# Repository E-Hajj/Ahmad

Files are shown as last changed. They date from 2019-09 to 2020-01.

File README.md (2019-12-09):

# Solar Panel Gazebo Build Instructions

## General info

This repository contains the implementation of a feasibility study for automatic readings of a solar panel. The project will heavily focus on measuring the current of the solar panel in Amps.

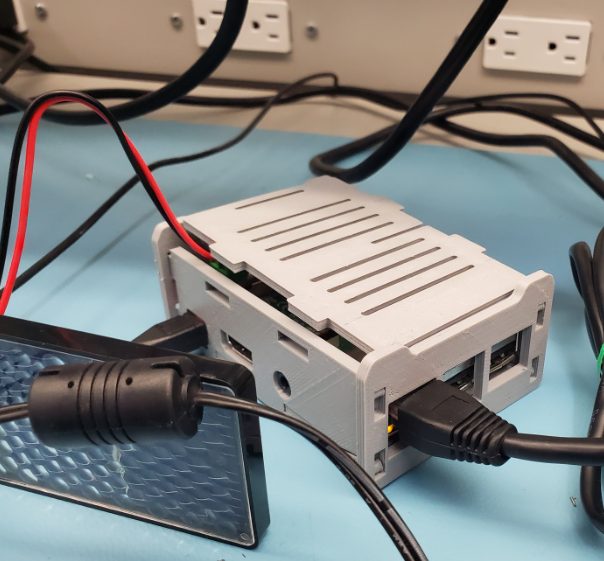
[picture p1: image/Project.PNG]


## Table of contents
* [General info](#general-info)
* [Repository Structure](#Repository-Structure)
* [Requirements](#Requirements)
* [PCB](#PCB)
* [3D Print](#3D-Printing)
* [Soldering](#Soldering)
* [Unit Testing](#Unit-Testing)
* [Assembly](#Assembly)
* [Product Testing](#Product-Testing)

## Repository Structure 

1.  [Documentation](https://github.com/E-Hajj/Ahmad/tree/master/documentation) of the solar repository.  
2.  [Code](https://github.com/E-Hajj/Ahmad/tree/master/Code) contains the source code to interact with the solar panel and sensors.   
3.  [Electronics](https://github.com/E-Hajj/Ahmad/tree/master/Electronics) holds the contents of the PCB design,schematic and breadboard design.  
4.  [Raspberry pi Case](https://github.com/E-Hajj/Ahmad/tree/master/Raspberry%20pi%20case) contains the required build for the case.  
5.  [Images](https://github.com/E-Hajj/Ahmad/tree/master/image) of the project.

## Requirements

In this project you will need the required components to build this project. The total budget is  $195.34 not including tax or shipping or any other fees and prices may rise or fall. Depending if you have amazon prime and able to go to Sayal Electronics your products should arrive 1 to 5 days. While waiting for your components to arrive i would recommended starting on the pcb and 3d printing.

* **Raspbery pi 3**   *$114*
  * Power supply 2A micro usb 
  * Ethernet cable and hdmi cable
  * Sd card for the software
  * If you dont own an raspberry pi 3 i would recommed buying one from [Amazon](https://www.amazon.ca/s?k=raspberry+pi+3&ref=nb_sb_noss_2) or [Sayal Electronics](https://secure.sayal.com/STORE2/index.php). 
* **Acs712 (current sensor)** *$13.99*
  * I would recoomend getting it from [Amazon](https://www.amazon.ca/COVVY-Current-Arduino-ACS712ELC-20A-Indicator/dp/B07TQ5M9MP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) becuase it comes in a pack of 2 incase one breaks or is faulty.  
* **Ads1115 (Analog to Digital Converter)** *$15.99*
   * [Amazon](https://www.amazon.ca/gp/product/B07GBYY54P/ref=ppx_yo_dt_b_asin_title_o04_s00?ie=UTF8&psc=1) would be a great option for this component, because the shipping is very quick for this.
* **Velleman Solar Cell 1V 200MA** *$7.95*
   * I would strongly recommend  [Sayal Electronics](https://secure.sayal.com/STORE2/index.php) sinces its cheaper and always in stock.
* **Wire Stripper/cutters** *$6.56*
  * If you already own them please make sure they work and are well sharpened.
   * [Amazon](https://www.amazon.ca/gp/product/B005HQR1YK/ref=ppx_yo_dt_b_asin_title_o02_s00?ie=UTF8&psc=1)
* **Safety eyewear** *$2.91*
  * Very important since you will be soldering and cutting and stripping wire 
  * Safety First
* **Soldering kit** *$29.99*
  * you will need some sort of soldering iron and solder to put together the PCB.
  * [Amazon](https://www.amazon.ca/gp/product/B07L3VNMKX/ref=ppx_yo_dt_b_asin_title_o03_s00?ie=UTF8&psc=1)
* **Socket kit** *$3.95*
  * 6 pin socket
  * 3 pin socket 
  * 10 pin socket
  * [Sayal Electronics](https://secure.sayal.com/STORE2/View_SHOP.php?SKU=241160)
  
 ## PCB
 I would strongly recommend ordering your parts before you continue on to this part. Usually the parts will take 3 to 5 days due to shipping unless you have amazon prime then it should take a day or two. While waiting for the parts you should start working on the breadboard and PCB board. Creating the PCB will take time depending where you get it made so i would strongly recommed that you get it made right away as it would take time.
 
 1. Go to [Electronics](https://github.com/E-Hajj/Ahmad/tree/master/Electronics) and download the Fritzing file of version two.
 2. When you open the File you will need to click on File->Export->Production->Gerber desing
 3. You will need to find a place that prints PCBs and get it made.
 4. while you wait on that you can start working on the breadboard. Looking at the fritzing file select the breadboard view and see how the circuit is made. 
 5. follow all the connections made. Even if you dont have the sensors you can have it all setup and ready.
 
 ## 3D Printing
 While you wait for the components to come in you can start working on the raspberry pi case. This folder will contain all the certian pieces need to assemble the case. It comes in like lego pieces that gets assembled together. This folder [Raspberry pi Case](https://github.com/E-Hajj/Ahmad/tree/master/Raspberry%20pi%20case) contains all the .stl files that needs printing. Download all the files needed.  
* [Back Panel](Raspberry%20pi%20case/back_panel_SD.stl)  
* [Bottom Panel](Raspberry%20pi%20case/bottom_panel.stl)  
* [Front Panel](Raspberry%20pi%20case/front_panel_USB.stl)  
* [Side Panel](Raspberry%20pi%20case/side_panel_GPIO_updated.stl)  
* [Side Panel HDMI](Raspberry%20pi%20case/side_panel_HDMI.stl)  
* [Top Panel](Raspberry%20pi%20case/top_panel.stl)  
 You will need a type of software that connects to 3d printers and reads .stl files. I would recommend [Cura](https://ultimaker.com/software/ultimaker-cura) since its very easy and simple to operate. 
 1. Open all the .stl files that you downloaded in Cura.
 
 2. Select the type of 3D printer you will be using.
 
 2. The top right Settings in Cura is the setting or style of the print it looks like this.
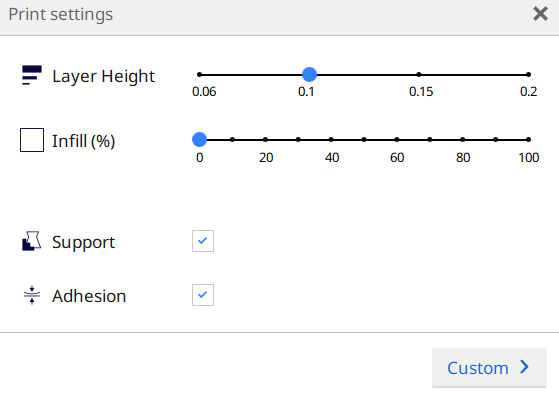
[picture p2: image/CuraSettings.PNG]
Cura
  
  
 3. Once completed you will need to press slice on the bottom right. Slice while create a .gcode file that will need to be uploaded to your 3d printer. Depending on your 3D printer you may need to upload it to an SD card and insert it in the printer. 
 
 4. Once placed you will need to select the file to start printing.  
 
 5. While printing please make sure you check on it every so often because the filler might run out or get stuck or the flat base plate might.

 ## Soldering 
 * If youve never soldered before i would recommend you to watch these videos on how to solder and safety as well. [Video](https://www.youtube.com/watch?v=BLfXXRfRIzY&list=PLQ32vZrF5U2lFOJTtZDytBWBYVLNp4RYz)
 1. When soldering the PCB make sure the 6 pin socket is at the bottom of the board.
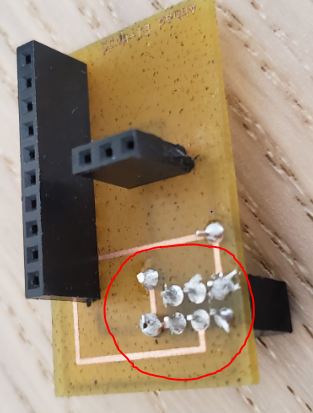
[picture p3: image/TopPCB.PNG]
 
 2. Line up the 10 and 3 pin sockets to their corresponding connection as seens in this picture, Then solder.
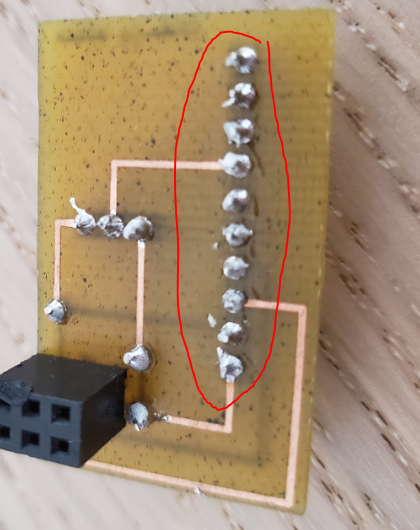
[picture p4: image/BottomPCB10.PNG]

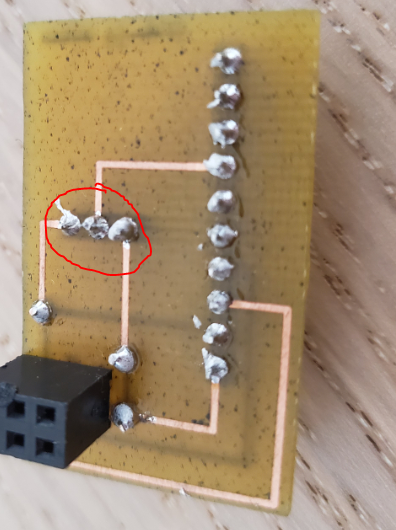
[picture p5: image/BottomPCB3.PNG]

 3. Solder All via's by runnings wire through it and soldering each side.
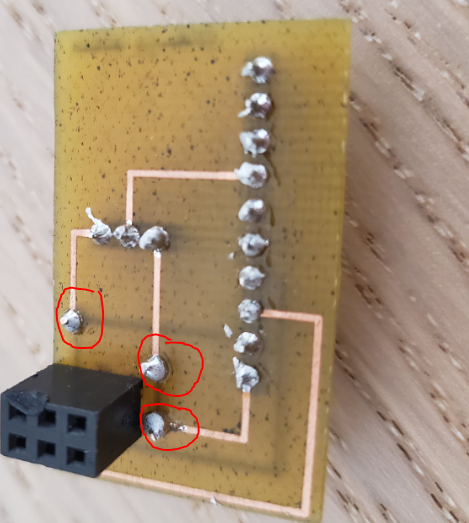
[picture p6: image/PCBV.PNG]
 

 4. Once completed you must check if all pins are fully covered in solder an are stable. 
 5. To make sure all connections are fine and the board isnt damage you must use a digital multi meter and measure the resistance between each ports. The readings should be overload for the ports that shouldnt be connected. The corresponding pin to pin should show a little resisitance.

 ## Unit Testing 
 
 Once all Parts have arrived you can start testing your sensors before you test them on the PCB board.  
 1. Setup  
     1.a if you havnt connected the parts on the breadboard please follow  [PCB](#PCB)   
     1.b You will need to be able to connect to your pi. If you havn't booted the operating sytem please follow this link. [Link]( https://www.raspberrypi.org/help/noobs-setup/2/)  
     1.c Once thats completed you will need to be able to connect the raspberry through ethernet or SSH. If you havn't done that or not sure please follow this guide. [Link](https://www.youtube.com/watch?v=oM2zVD9rL8I)   
 
 2. Testing the Sensors  
 
     2.a You will need to install some of the code and libraries, so please type these command lines   
     
     ```sudo apt-get update```  
     ```sudo apt-get install build-essential python-dev python-smbus git```  
     ```cd ~```  
     ```git clone https://github.com/adafruit/Adafruit_Python_ADS1x15.git```  
     ```cd Adafruit_Python_ADS1x15```  
    ``` sudo python setup.py install```  
     
     2.b we will need to install the python package index please follow and type these command lines
     
     ```sudo apt-get update```  
     ```sudo apt-get install build-essential python-dev python-smbus python-pip```  
     ```sudo pip install adafruit-ads1x15```  
     
     2.c Now we will run the simpleTest.file to test the sensors 
     
     ```cd ~/Adafruit_Python_ADS1x15/examples```
     ```nano simpletest.py```

    3. The ouput
     ![Readings]( image/Readings.png)  

     4. For any errors please follow this [Link](https://learn.adafruit.com/raspberry-pi-analog-to-digital-converters/ads1015-slash-ads1115)

 ##  Assembly
 Now since everything is working we will now put everything together.
 1. We will be putting the case pieces together to enclose our raspberry pi.
 2. We will need to grab the front piece of the raspberry pi and connect the two side together. 
  ![PCB](image/sidepanel.PNG)
 
 * **Make sure you pinch the side to be able to fit them in**
 
 3. Once its stable you will now connect the base piece to the two sides
   ![PCB](image/case3.PNG)
 4. Now you will to place the raspberry pi inside the case.  
 
 5. Connect the back piece of the case and remember to pinch the connections to be able to fit them 
 ![PCB](image/case5.PNG)
 6. now plug in the PCB board that you soldered. Make sure you place it in the first 6 pins as seen in this picture.
 ![PCB](image/case6.PNG)
 7. unscrew the the Acs712 to be able to connect the wires of the solar panels.
 ![PCB](image/sensorScrew.PNG)
 8. plug in the Analog to Digital(ADC) in the sockets.
 ![PCB](image/case6.PNG)
 9. final step to place the cover of the top of the raspberry pie with the top piece.
 ![PCB](image/case7.PNG)

 ## Product Testing 
 If we were to produce 1000 units we will need to build and test these projects differently. In productions all parts and required pieces will bought in bulk. Once the PCB's are made they will be tested shortly after they are made. We will have a custom board with pins that will test the PCB before they are soldered. While they get soldered the Pins will test if they are fully covered and are able to transmitt some power through each pin. All sensors will be tested on a custom breadboard and tested to see if they are functioning. 3D prints will be made and assembled at the end to see if the case fits its not clipping then the 3D print needs to be printed again.

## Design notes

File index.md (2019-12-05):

Solar Panel Gazebo
---------------

## December 5 2019 (Week 14)
-------------------
Worked on the build instructions completed %60 so far
Uploaded vidoes of the readings in the images folder.

### November 28 2019 (Week12
------------------------
Presetation time 1:35
completed demonstration of readings with sensor
Presentation completed 
[Presentation](Presentation/Ahmad%20Presentation%20Hardware%20-%20Copy.pptx)

### November 20 2019 (Week 11)
-----------------
Case Has been 3D printed and assembled.The only issue i have is the lid wont fit due to the high of the pcb and sensors. I will be making a version 2 to properly enclose the raspberry pi.\
[Back Panel](Raspberry%20pi%20case/back_panel_SD.stl)\
[Bottom Panel](Raspberry%20pi%20case/bottom_panel.stl)\
[Front Panel](Raspberry%20pi%20case/front_panel_USB.stl)\
[Side Panel](Raspberry%20pi%20case/side_panel_GPIO_updated.stl)\
[Side Panel HDMI](Raspberry%20pi%20case/side_panel_HDMI.stl)\
[Top Panel](Raspberry%20pi%20case/top_panel.stl)
PCB
PCB
PCB
### November 14 2019 (Week 10)
-----------------

Progress Report
-----
This semester has been going very well so far. The proposal and Schedule were straight forward and required a little bit of research. Currently my financial status did have to change due to me realizing I need a few items along the way. I should’ve done a bit more research on what I have and what I will need over time. For example, I needed sockets and wire strippers. Currently I am over budget by ten dollars. Parts did come on time since I used amazon and local electronic stores. PCB design wasn’t an issue at first until I noticed that some of the wires were on the side of the board. The problem was noticed after soldering the board and realizing it and receiving feedback on how to fix the PCB. The PCB design did require some adjustments which led to a version two. Beard board milestone did take me a while to figure out why my sensors weren’t able to show their readings. It required me to change the code multiple of times to finally get it working. Majority of the progress has been perfectly on time and on schedule. The only thing I’m off schedule is the PCB soldered due to me requiring a version too. While I was waiting for version two of the PCB to be made, I decided to work on the case and get it ready of ahead of time thus making me not behind on future progresses. The PCB powered up will be demonstrated next week. The remaining work left is to complete my case design and have it ready as soon as possible so if I do have an issue, I won’t be behind. PCB testing and presentation are the remaining progresses. Therefore, all my progresses are on my repository and posted in the website to indicate what has been completed and will update the repository even more in the future.

### November 7 2019 (Week 9)
-----------------
The PCB Design of version one had issues with the current sensor layout. Wires were also place in the wrong position some were supposed to be on the top and some where supposed to be at the bottom so they have a proper connection to the sockets.
Version 2 of PCB has been made created [Version 2](Electronics/Version%202). And Hast also been sent to the prototype lab and will be soldered.
PCB
PCB

### October 31 2019 (Week 8)
-----------------
Sensors are working and are being displayed

Created [Readings Code](Code/simpletest.py).
Readings

### October 24 2019 (Reading Week)
-----------------
-Raspberry pi boot up
-able to ssh the raspberry pi through ethernet cable and through wifi.

### October 17 2019 (week 7)
------------
Created [PCB Design](https://github.com/E-Hajj/Ahmad/tree/master/Electronics).
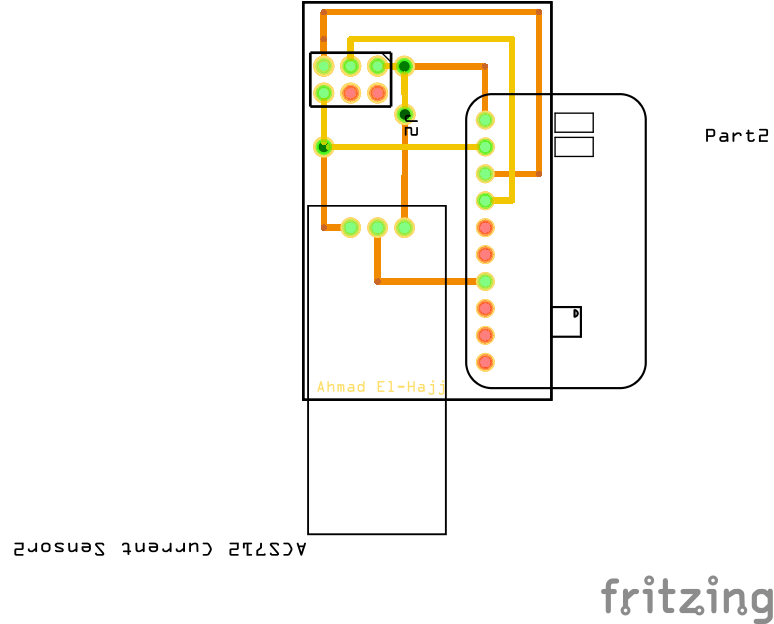
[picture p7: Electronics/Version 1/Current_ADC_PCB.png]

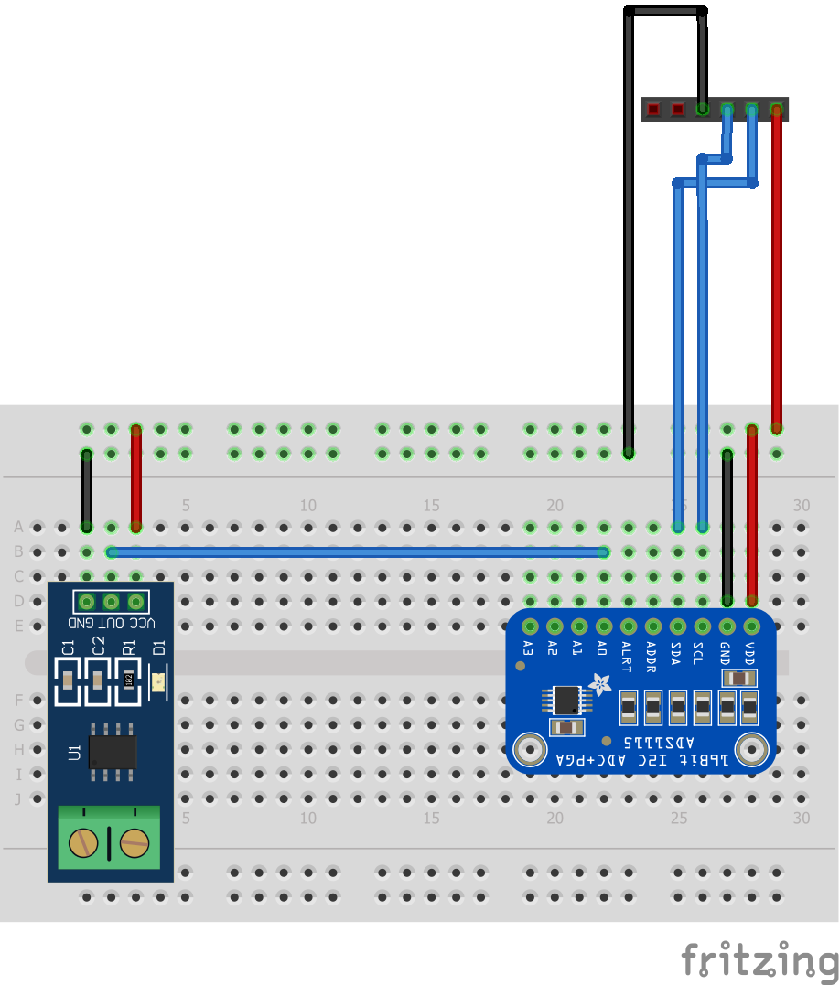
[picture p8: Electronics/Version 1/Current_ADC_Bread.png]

### October 10 2019(Week 6)
--------------------------
Show your acquisitions/Check in meeting

### October 3 2019(Week 5)
-------------------
Proof of Payement 

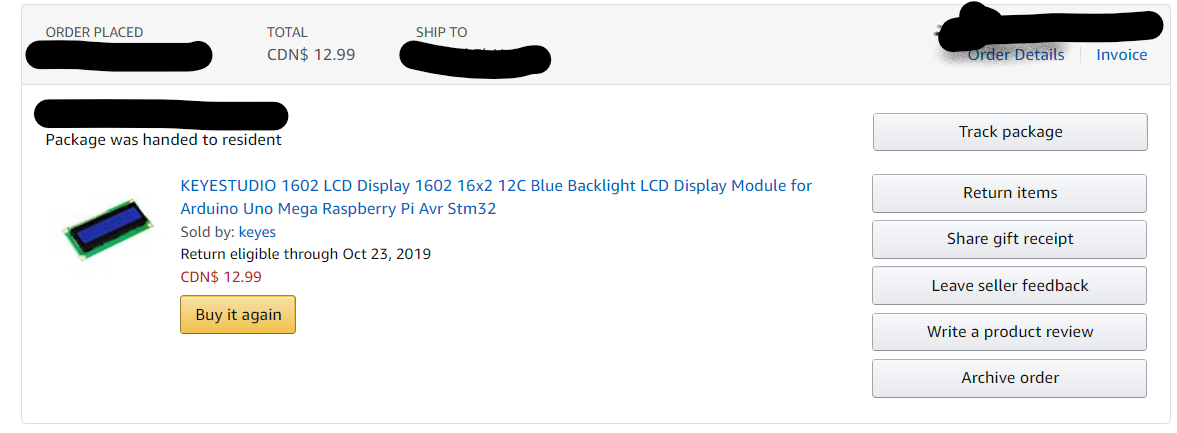
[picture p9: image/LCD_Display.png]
LCD Display

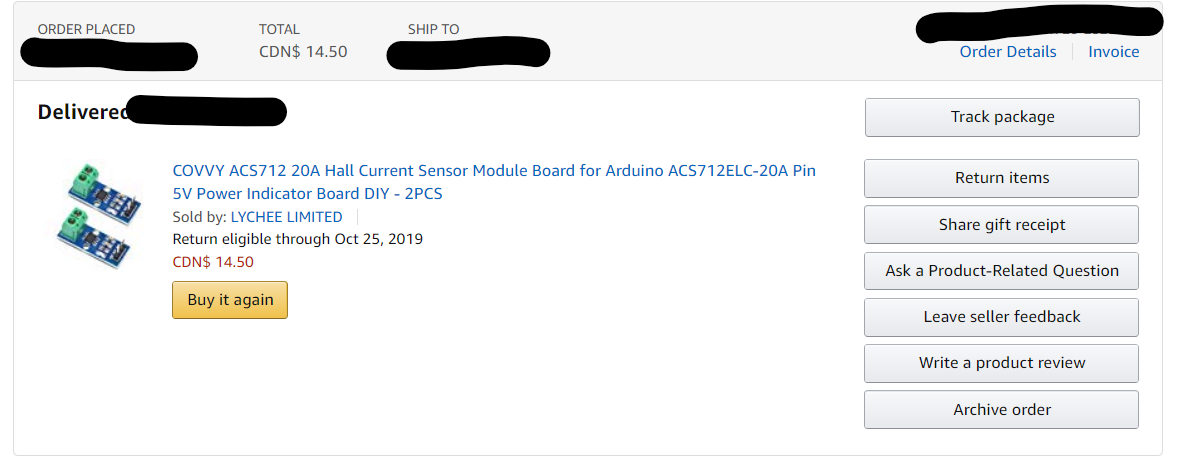
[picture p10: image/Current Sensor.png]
Image Cureent Sensor

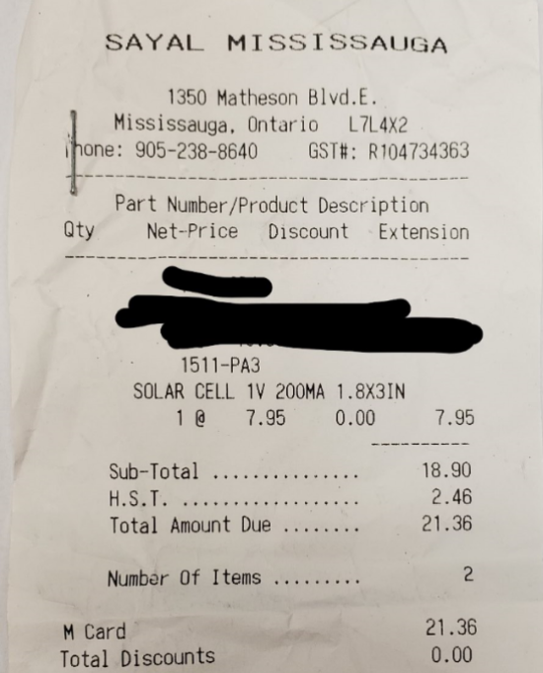
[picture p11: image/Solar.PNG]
Image Solar


### September 26 2019 (Week 4)
--------------------
Completed my [budget](documentation/Budget.pdf)

### September 19 2019 (Week 3)
----------------------------
Created [Project Schedule](documentation/ProjectSchedule.pdf).

### September 12 2019 (Week 2)
---------------------------
Created [Proposal](documentation/AhmadEl-HajjCENG317As1.pdf).

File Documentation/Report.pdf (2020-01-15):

# M.A.R.S Inc Solar Panel

# Monitoring System

### Ahmad El-Hajj

## Declaration of Joint Authorship

We, Ahmad, Ramin, and Matthew, confirm that this work submitted is the joint work of

our group and is expressed our own words. Any uses made within it of the works of any

other author, in any form (ideas, equations, figures, texts, tables, programs), are properly

acknowledged at the point of use. A list of the references used is included. The work

breakdown is as follows: Each of us provided functioning, documented hardware for a

sensor or effector. Student A provided Ahmad El-Hajj. Student B provided Ramin Kurkeice.

Student C provided Matthew Phillip. In the integration effort Student A is the lead for

further development of our mobile application, Student B is the lead for the Hardware,

and Student C is the lead for connecting the two via the Database.

## Proposal

We have created a mobile application, web application, worked with databases,

completed a software engineering course, and prototyped a small embedded system

with a custom PCB as well as an enclosure (3D printed/laser cut). Our Internet of

Things (IoT) capstone project uses a distributed computing model of a smart phone

application, a database accessible via the internet, an enterprise wireless (capable of

storing certificates) connected embedded system prototype with a custom PCB as well

as an enclosure (3D printed/laser cut), and are documented via this technical report

targeting OACETT certification guidelines. The project has been split into three parts:

hardware, software and back end(database). Software consists the mobile application

to display readings and the web application which will display the readings and display

them in a graph and will show previous readings. Hardware will consist the following

sensors shown below, and the raspberry pi three. Backend will use MySQL to store the

database.

Intended project key component descriptions and part numbers

Development platform:

Sensor/Effector 1: ACS 712 Current

Sensor/Effector 2: ZMPT101B Voltage

Sensor/Effector 3: LM35 Temperature

We will continue to develop skills to configure operating systems, networks, and

embedded systems using these key components to measure the voltage, current and temperature. Once we receive the following values, they will be uploaded to the

database to be displayed on a mobile application and web application.

Our project description/specifications will be reviewed by, Dragos Paraschiv, ideally an

employer in a position to potentially hire once we graduate. They will also ideally attend

the ICT Capstone Expo to see the outcome and be eligible to apply for NSERC funded

extension projects. This typically means that they are from a Canadian company that

has been revenue generating for a minimum of two years and have a minimum of two

full time employees.

The small physical prototypes that we build are to be small and safe enough to be

brought to class every week as well as be worked on at home. In alignment with the

space below the tray in the Humber North Campus Electronics Parts kit the overall

project maximum dimensions are 12 13/16" x 6" x 2 7/8" = 32.5cm x 15.25cm x 7.25cm.

Keeping safety and Z462 in mind, the highest AC voltage that will be used is 16Vrms

from a wall adapter from which +/- 15V or as high as 45 VDC can be obtained.

Maximum power consumption will not exceed 20 Watts. We are working with prototypes

and that prototypes are not to be left powered unattended despite the connectivity that

we develop. Devices and components will always be tested before assembled and

connected together. Safety training has been provided by Humber to help ourselves

safe and others safe by our actions. Safety glasses are worn at all times when working

on the projects and in the workshop. Safety precautions are taken when using the

following sensors, following the manufactures guidelines. Safety soldering tips and

training have been provided as well to ensure our PCB’s are functional and remain safe

at all times.

## Executive Summary

We have created a solar panel monitoring device to measure live readings of the solar

panel. This product will help determine how efficient solar panels are and see results

throughout the day. Data is currently being uploaded through a mobile application and a

website showing the results of voltage, current and temperature. This product will also

guide any user who needs to monitor their solar panel. Having the required knowledge

and experience will help the employer produce a successful and well-functioning solar

panel monitoring system with a clean and simple mobile application and web server.

## Contents

## List of Figures

Figure 7. By Android Studio - https://developer.android.com/studio/, CC BY-SA 4.0,

Figure 1. Initial schematic. This work is a derivative of "http://fritzing.org/parts/" by

Figure 2. This work is a derivative of "http://fritzing.org/parts/" by Fritzing, used under

Figure 4. PCB design This work is a derivative of "http://fritzing.org/parts/" by Fritzing,

## 1.0 Introduction

Idea. Self-driving cars using Machine Learning. Scope and Requirements specification.

Project Schedule.

1.1 Scope and Requirements

Describe what will be done. It is an Internet of Things (IoT) capstone project that uses a

distributed computing model of a smart phone application, a database accessible via

the internet, an enterprise wireless (capable of storing certificates) connected

embedded system prototype with a custom PCB as well as an enclosure (3D

printed/lasercut), and is documented via an OACETT certification acceptable technical

report. Also describe the limits of the project and what will not be done (CSA testing) in

this project. Include the development platform specifications and any other hardware

specifications possibly organized in point form, the Android device requirements, and

database specifications/protocols.

Report

/1 Hardware present?

/1 Introduction (500 words)

/1 Scope and Requirements

/1 Background (500 words)

/1 References

## 2.0 Background

We would like to thank mentor Diego Magalhães from AWS for supporting this project.

This section is to include at least three references, here is an example of an APA

citation of a website (OACETT, 2017) followed by a sentence citing an Article in a

Periodical, a Book, and a Journal Article. Humber is planning to host an internal

DeepRacer event using an existing example of machine learning (Robuck, 2018),

artificial intelligence (Media, O., 2019), and internet connected servers (Kinsella, 2019).

## 3.0 Methodology

3.1 Required Resources

Report

/1 Parts/components/materials (500 words)

/1 PCB, case (500 words)

/1 Tools, facilities (500 words)

/1 Shipping, duty, taxes (250 words)

/1 Working time versus lead time (250 words)

3.1.1 Parts, Components, Materials

3.1.2 Manufacturing

3.1.3 Tools and Facilities

3.1.4 Shipping, duty, taxes

3.1.5 Time expenditure

Working time versus lead time.

3.2 Development Platform

3.2.1 Mobile Application

Status

/1 Hardware present?

/1 Memo by student A + How did you make your Mobile Application? (500 words)

/1 Login activity

/1 Data visualization activity

/1 Action control activity

Include screenshots such as Figure 1. Testing. Progress.

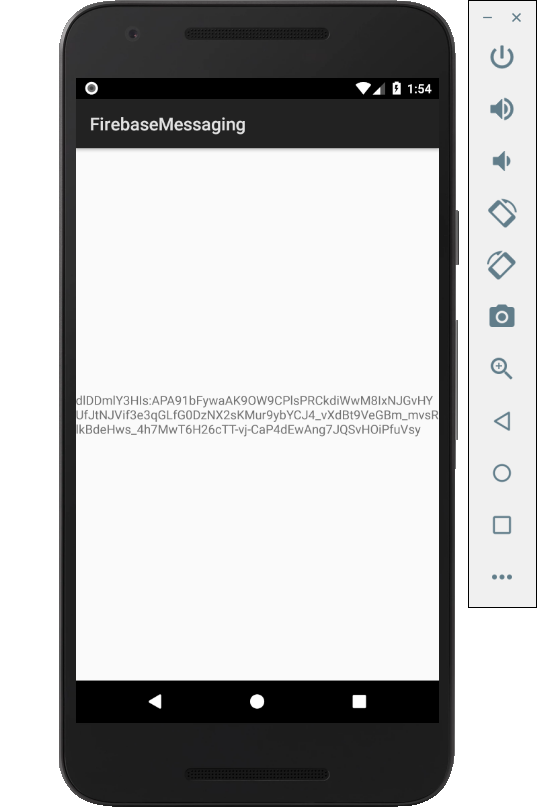
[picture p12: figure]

Figure 1. By Android Studio - https://developer.android.com/studio/, CC BY-SA 4.0, https://commons.wikimedia.org/w/index.php?curid=74094999
3.2.2 Image/firmware

Status

/1 Hardware present?

/1 Memo by student B + How did you make your Image/firmware? (500 words)

/1 Code can be run via serial or remote desktop

/1 Wireless connectivity

/1 Sensor/effector code on repository

3.2.3 Breadboard/Independent PCBs

Status

/1 Hardware present?

/1 Memo by student C + How did you make your hardware? (500 words)

/1 Sensor/effector 1 functional

/1 Sensor/effector 2 functional

/1 Sensor/effector 3 functional

The initial schematic design, Figure 2, based on datasheets (Bosch Sensortec, 2019)

led to a breadboard layout Figure 3 that was realized Figure 4.

How did you build your Prototype: Breadboard?

Then a PCB was designed, Figure 5, and populated (Figure 6). Bill of Materials, Case,

Time commitment. Testing. Progress.

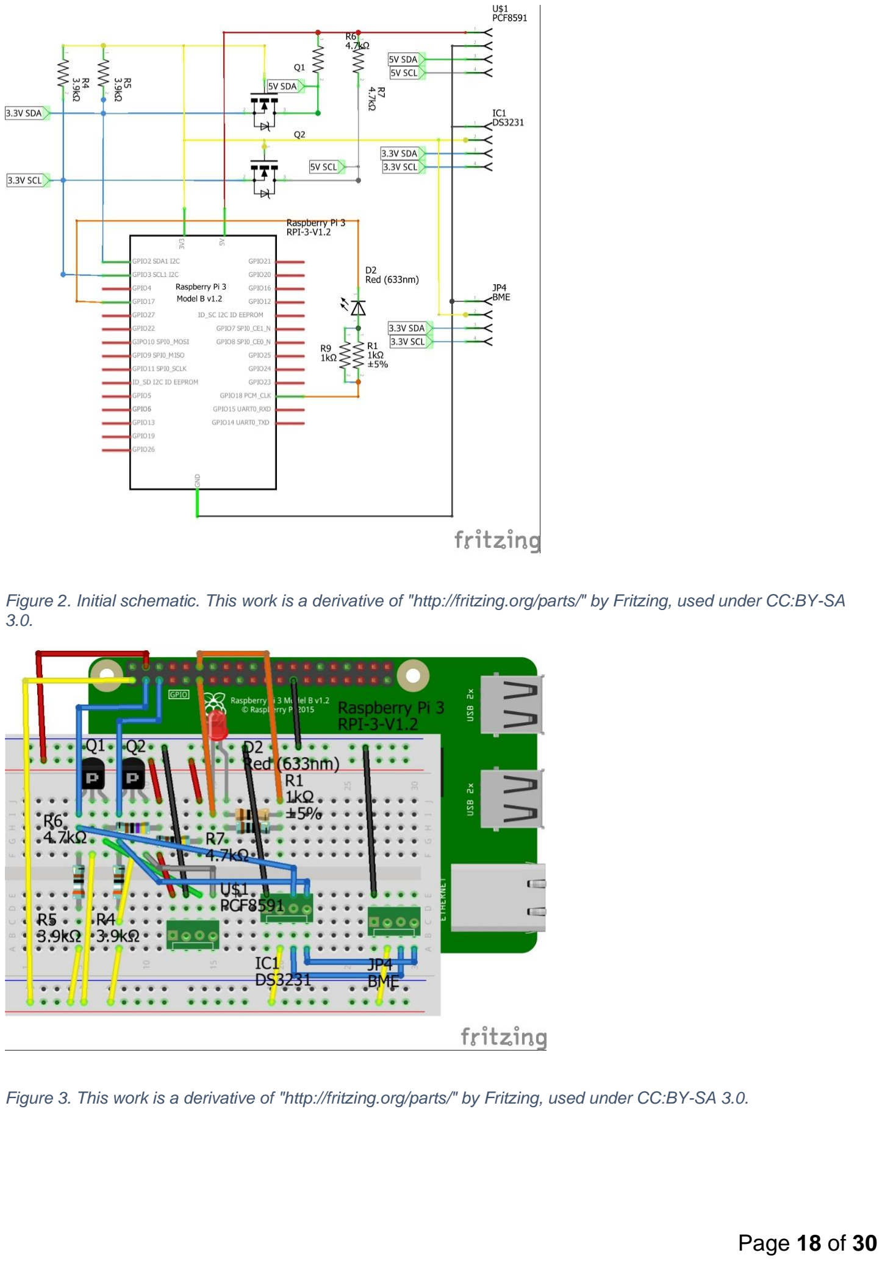
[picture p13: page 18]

Figure 2. Initial schematic. This work is a derivative of "http://fritzing.org/parts/" by Fritzing, used under CC:BY-SA 3.0.

Figure 3. This work is a derivative of "http://fritzing.org/parts/" by Fritzing, used under CC:BY-SA 3.0.

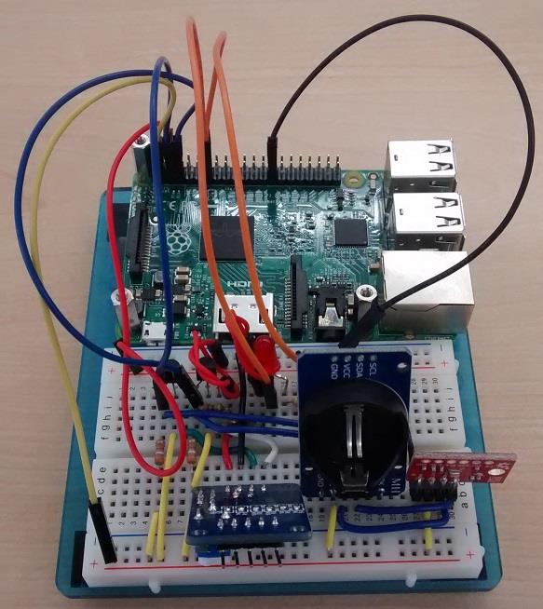
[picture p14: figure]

Figure 4. Breadboard prototype.
3.2.4 Printed Circuit Board

Demo

/1 Hardware present?

/1 PCB Complete and correct

/1 PCB Soldered wire visible but trim, no holes or vacancies

/1 PCB Tested with multimeter

/1 PCB Powered up

How did you build your Prototype: PCB?

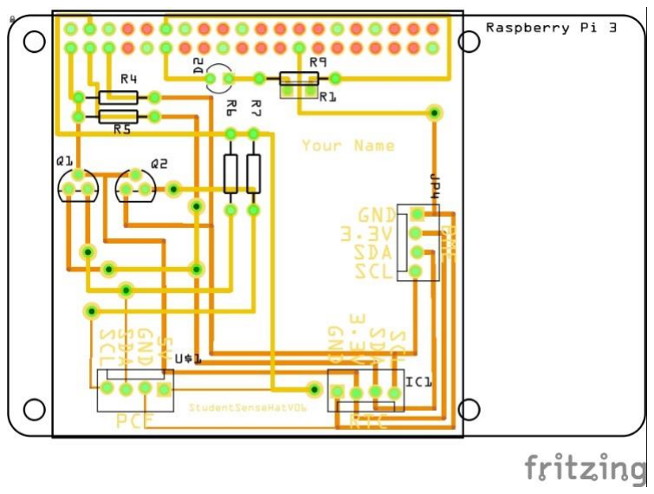
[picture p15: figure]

Figure 5. PCB design This work is a derivative of "http://fritzing.org/parts/" by Fritzing, used under CC:BY-SA 3.0.

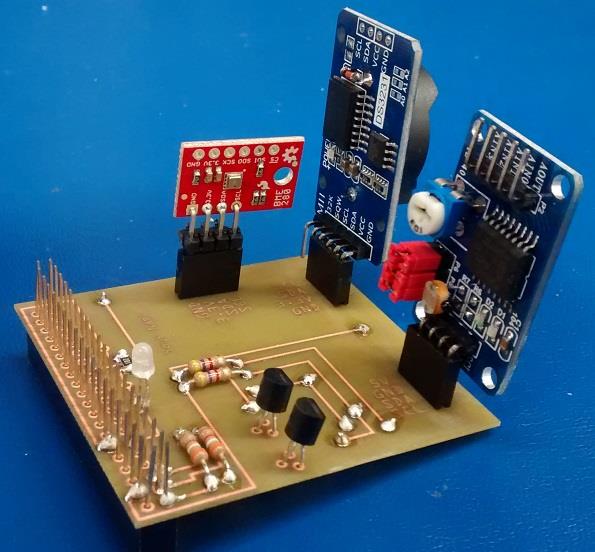
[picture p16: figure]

Figure 6. Humber Sense Hat Prototype PCB.
3.2.5 Enclosure

Demo

/1 Hardware present?

/1 Case encloses development platform and custom PCB.

/1 Appropriate parts securely attached.

/1 Appropriate parts accessible.

/1 Design file in repository, photo in report.

How did you build your Prototype: Case?

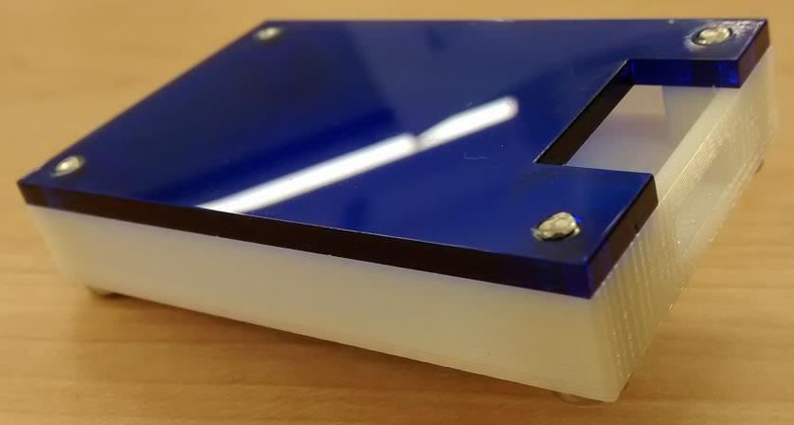
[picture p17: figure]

Figure 7. Example enclosure.
3.3 Integration

Demo

/1 Hardware present?

/1 Data sent by hardware

/1 Data retrieved by mobile application

/1 Action initiated by mobile application

/1 Action recieved by hardware

Report

/1 Enterprise wireless connectivity (250)

/1 Database configuration (250 words)

/1 Security considerations (500 words)

/1 Unit testing (900 words)

/1 Production testing (100 words)

3.3.1 Enterprise Wireless Connectivity

How did you make a Database accessible by both your Prototype and Mobile

Application?

3.3.2 Database Configuration

3.3.3 Security

3.3.4 Testing

Unit testing and Production testing.

## 4.0 Results and Discussions

Is your prototype perfect? What did you learn?

## 5.0 Conclusions

If you were making 1000 of these.

Report

/1 Hardware present?

/1 Checklist truthful

/1 Valid Comments

/1 Results and Discussion (500 words)

/1 Conclusion

## 6.0 References

Bosch Sensortec. (2019, July). BME680 - Datasheet. Retrieved from Robert Bosch

GmbH: https://ae-bst.resource.bosch.com/media/_tech/media/datasheets/BST-

BME680-DS001.pdf

Kinsella, J. (2019). Five trends predicted for the cloud industry in 2019. Software World,

50(1), 11.

Media, O. (2019). O'Reilly artificial intelligence conference 2019 - San Jose, California.

California: O'Reilly Media, Inc.

OACETT. (2017, March). I need to Complete a Technology Report. Retrieved from The

Ontario Association of Certified Engineering Technicians and Technologists:

https://www.oacett.org/Membership/Technology-Report-and-Seminar

Robuck, M. (2018, 11). AWS goes deep and wide with machine learning services and

capabilities. Fierceinstaller.

## 7.0 Appendix

7.1 Firmware code

Demo

/1 Hardware present?

/3 Code runs concurrently for all sensors/effectors

/1 Project repository contains integrated code

Status

/1 Memo including updates

/1 Financial update

/1 Progress update

/1 Modified Code Files in Appendix

/1 Link to Complete Code in Repository

7.2 Application code

Demo

/1 Hardware present?

/1 Memo by student A

/1 Login activity

/1 Data visualization activity

/1 Action control activity

Report

/1 Login activity

/1 Data visualization activity

/1 Action control activity

/1 Modified Code Files in Appendix

/1 Link to Complete Code in Repository

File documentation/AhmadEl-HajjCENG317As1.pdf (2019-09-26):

Submission date | 9/12/19
Project name | L-wing solar power interactive display
Students Name | Ahmad El-Hajj. Group Members: Mathew Phillip, Ramin Kurkeice
Sensor effectors | Luminosity sensor
How data will be stored | Data will be collected every 30 minutes.
Mobile function | Collects data and displays it in a graph over time and keeps it stored for at least a year
Problem statement | The L-Wing has solar panels installed on the roof. Humber wants to know how much power is collected every 30 minutes. Humber wants to access this data through a website and an app.
Background | The project will be split into three parts. One member will be in charge of the UI part which will be the app and website interface. The second group member will be in charge of the controller which would be the hardware part. The third group member will be in charge of the database. The member in charge of the database will create a database and connect it to the website and app.
Research IEE paper APA citation | Choi, Charles Q. “Full Page Reload.” IEEE Spectrum: Technology, Engineering, and Science News, 1 July 2019, spectrum.ieee.org/energywise/energy/the-smarter-grid/best-algorithms-to-make-solar-power-profitable.
Planned purchases | Raspberry pi(min second gen ),solar-PV panels, power optimizers, EV Charger
Solution | VMD method is the best option to complete this assignment

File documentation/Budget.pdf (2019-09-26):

Ahmad El-Hajj N01247366 | MARS INC Budget
Description | Source | Part # | CAD Unit Cost | USD Unit Cost | Number of units | Link | Comments
Covy Current Sensor Module Board for Arduino | Amazon | ACS712 | $14.50 | 2 | https://www.amazon.ca/gp/product/B07TQ5M9MP
KEYESTUDIO LCD Display 16x2 | Amazon | | $12.99 | 1 | https://www.amazon.ca/gp/product/B0177XQE7K
Gikfun 9v Battery Holder with ON/Off Switch | Amazon | EK2107x2C | $10.98 | 2 | https://www.amazon.ca/gp/product/B07G583G88
Amazon Shipping | Amazon | | $0 | | | Student Prime
Amazon Tax | Amazon | | $0 | | | Taxes were already included in the price
Coupon | Amazon | | -$1 | | | Gikfun battery holder had a $1 off coupon
Velleman Solar Cell 1V 200MA | SAYAL Electronics | 1.8x3IN | $7.95 | 1 | Location= 1350 Matheson Blvd.E
Transportation | SAYAL Electronics | | $2 | | Location= 1350 Matheson Blvd.E | Price of gas used
DURACELL 9V Battery | Owned | | $0 | 1
Wire Strippers | Owned | | $0 | 1
CanaKit Raspberry Pi 3 Ultimate Starter Kit | Owned | 99153 | $0 | 1 | Purchased 2 years ago
2.5A Power Adapter | Owned | | $0 | 1 | Came with Raspberry pi
LEDs | owned | | $0 | 8 | Came with Raspberry pi
Adruino Uno R3 Atmega328P | Owned | EL-CB-001 | $0 | 1 | Purchased a year ago.
Adruino Uno USB cable | Owned | | $0 | 1 | Came with the product
Total for parts from US sources | $0
CAD$ Total | $47.67

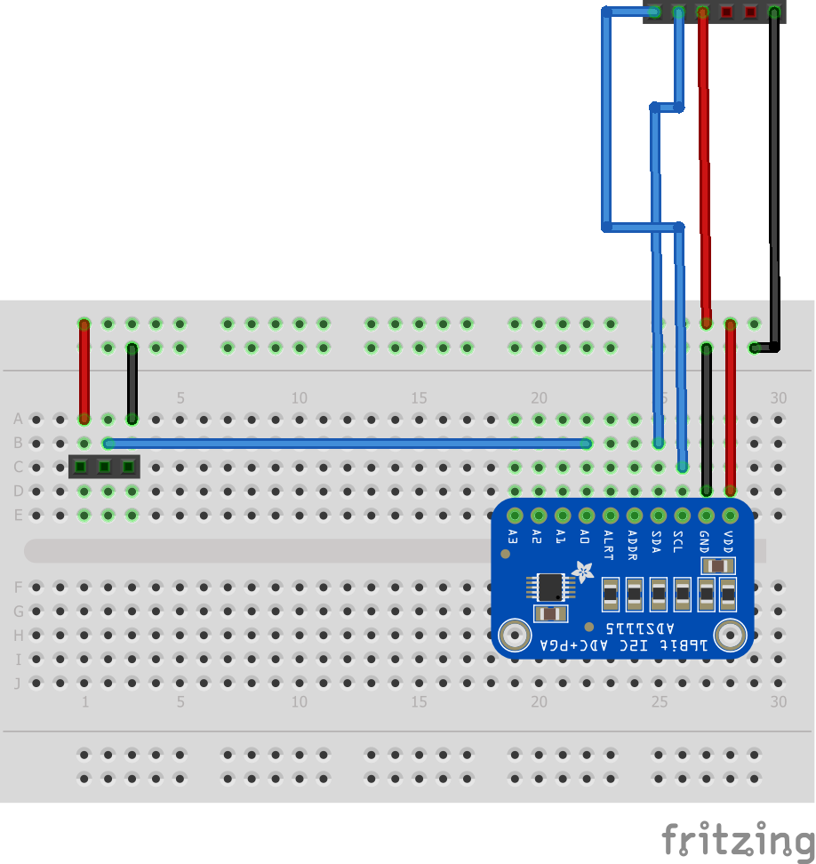
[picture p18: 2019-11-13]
Electronics/Version 2/Current_ADC_bbV2.png

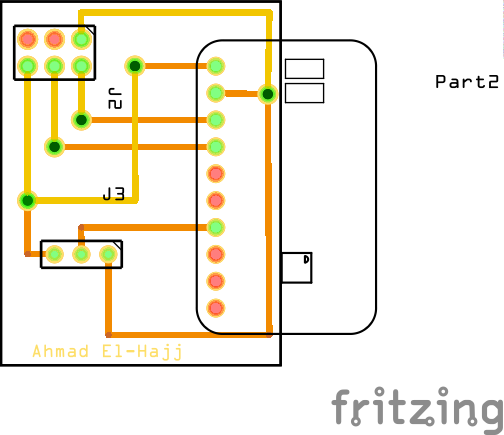
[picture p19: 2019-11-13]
Electronics/Version 2/Current_ADC_pcbV2.png

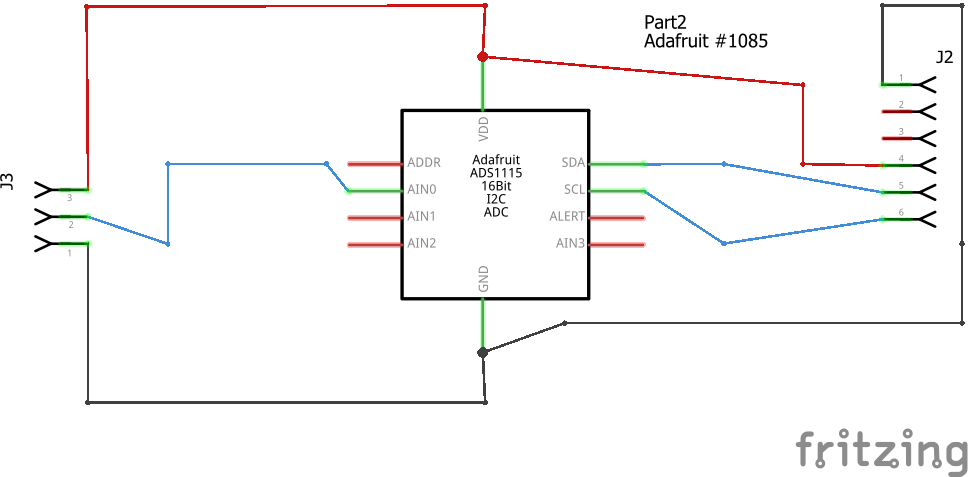
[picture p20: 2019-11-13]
Electronics/Version 2/Current_ADC_schemV2.png

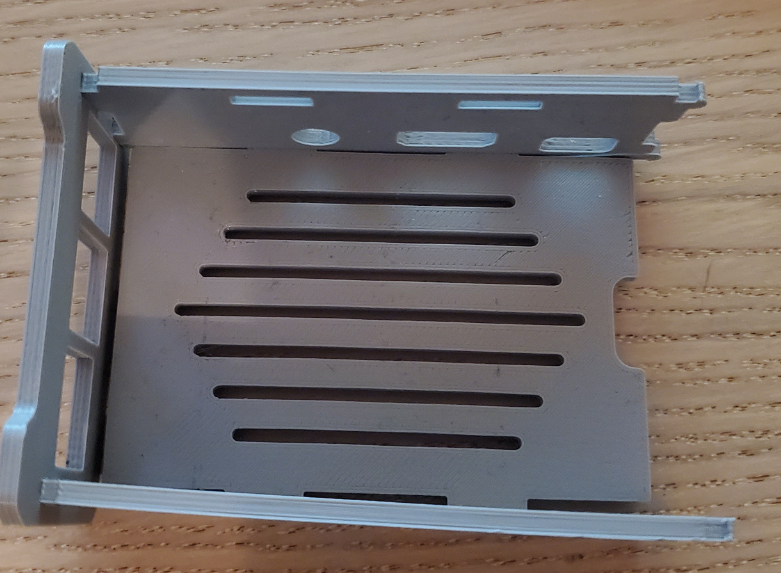
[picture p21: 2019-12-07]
image/case3.PNG

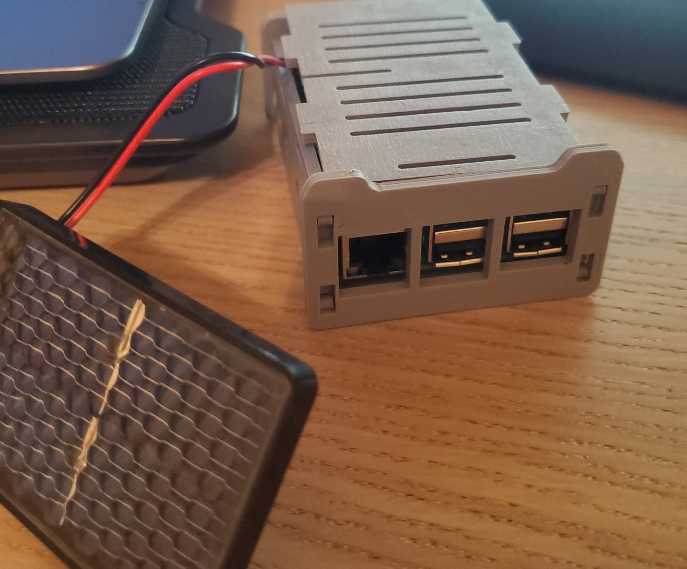
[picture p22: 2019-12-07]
image/case7.PNG

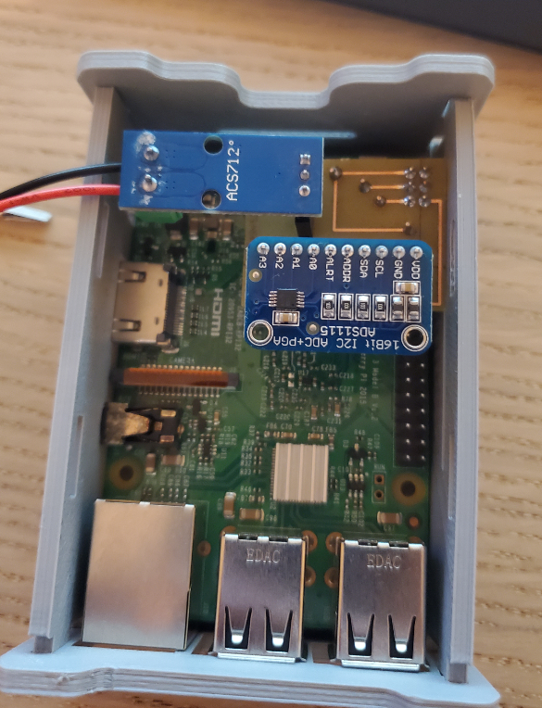
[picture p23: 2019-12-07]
image/case6.PNG

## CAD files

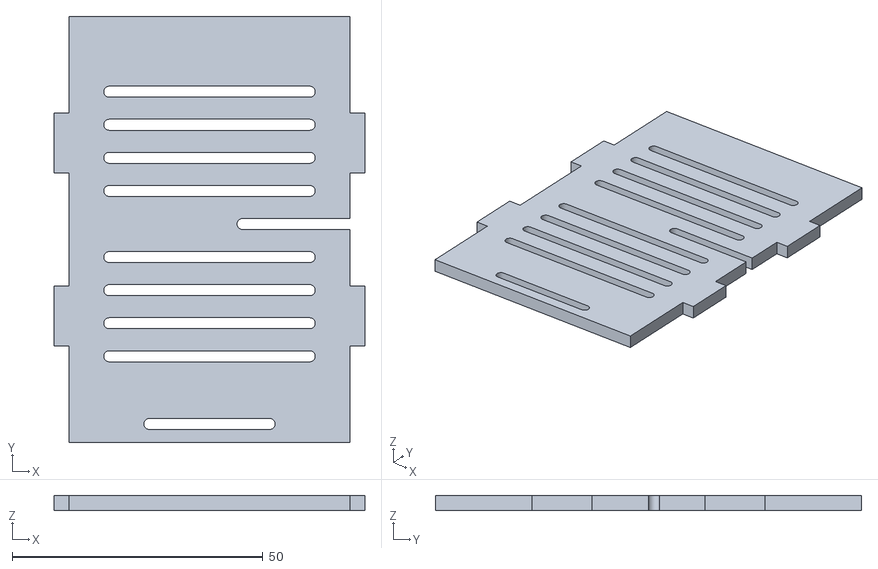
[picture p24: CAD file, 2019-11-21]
Raspberry pi case/top_panel.stl
62.0 x 85.0 x 3.00

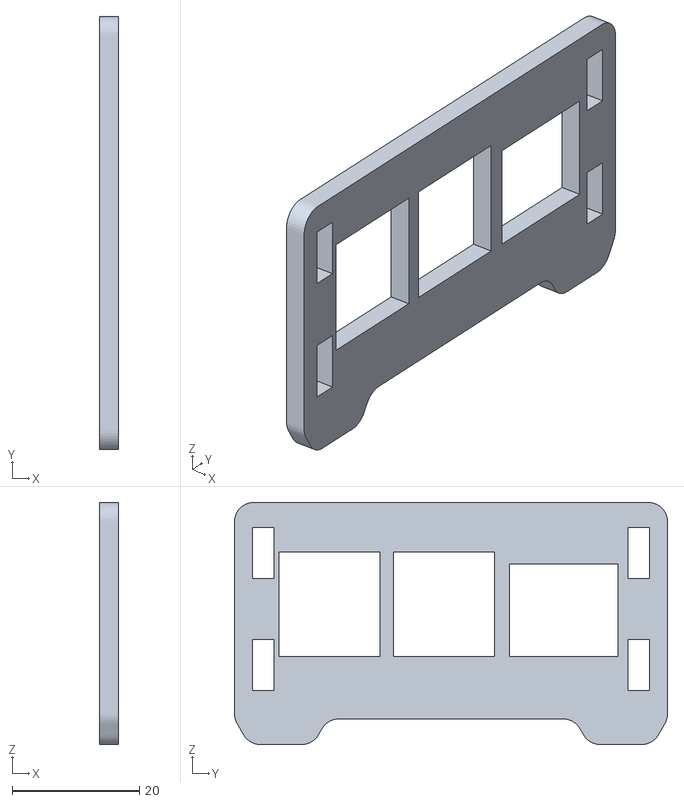
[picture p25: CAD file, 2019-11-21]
Raspberry pi case/front_panel_USB.stl
3.00 x 68.0 x 38.0

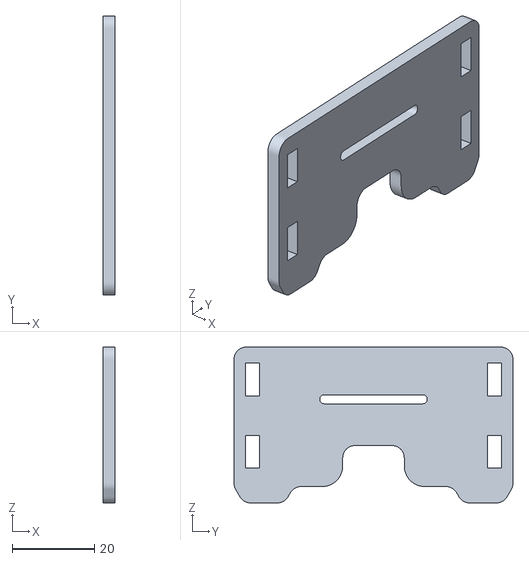
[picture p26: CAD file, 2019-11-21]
Raspberry pi case/back_panel_SD.stl
3.00 x 68.0 x 38.0

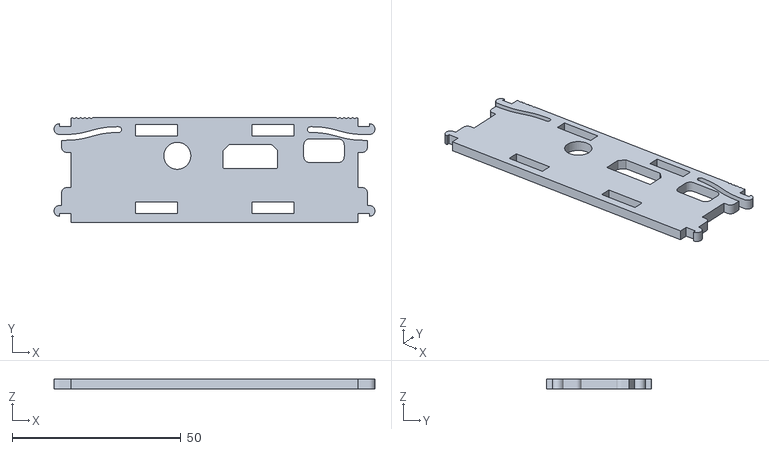
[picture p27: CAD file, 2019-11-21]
Raspberry pi case/side_panel_HDMI.stl
95.0 x 31.0 x 3.00

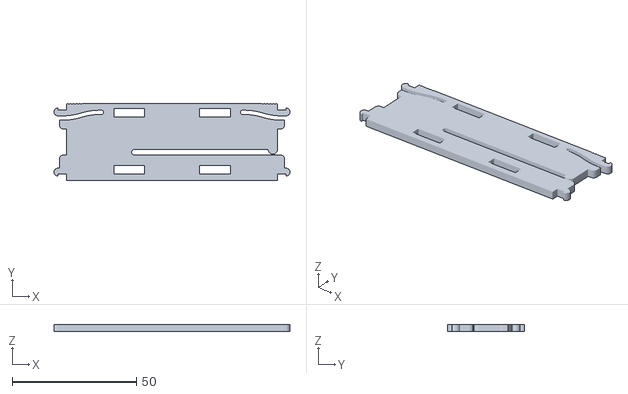
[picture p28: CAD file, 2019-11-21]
Raspberry pi case/side_panel_GPIO_updated.stl
95.0 x 31.0 x 3.00

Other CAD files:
Raspberry pi case/bottom_panel.stl

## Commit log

2019-11-13 PCB image
2019-11-13 PCB images Version 1
2019-11-21 pi case
    [back_panel_SD.stl, bottom_panel.stl, front_panel_USB.stl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]
2019-12-06 soldering pics
